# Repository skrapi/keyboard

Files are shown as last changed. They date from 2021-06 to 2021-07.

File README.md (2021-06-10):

# keyboard
Documenting my mechanical keyboard build

1. Put feet on case
1. Cut foam for M2 chip
1. Placed M2 Chip in keyboard
1. Plugged in computer
1. Flashing blue light on "1" key
1. Spacebar works
1. https://www.youtube.com/watch?v=usNx1_d0HbQ&t=84s
1. https://www.youtube.com/watch?v=cD5Zj-ZgMLA
1. Decided just to clip stabs, since I don't have lube
1. Mounted stabs with plastic washers
1. connected bluetooth and nfc antennas
1. Make sure that thehy are not in the way of the pcb mounting and switch connection holes
1. Cut case if needed to fit M2 boarD
1. Tested with online keyboard tester
1. Placed all the keycaps

## Designing keyboard
https://github.com/ruiqimao/keyboard-pcb-guide

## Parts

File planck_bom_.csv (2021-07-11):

Component | Description | Part | References | Value | Footprint | Quantity Per PCB | Datasheet
1 | Unpolarized capacitor, small symbol | C_Small | C7 C9 | 18p | C_0603_1608Metric | 2 | ~
2 | Unpolarized capacitor, small symbol | C_Small | C1 C2 C3 C4 C8 | 0.1u | C_0603_1608Metric | 5 | ~
3 | Unpolarized capacitor, small symbol | C_Small | C6 | 1u | C_0603_1608Metric | 1 | ~
4 | Unpolarized capacitor, small symbol | C_Small | C5 | 4.7u | C_0603_1608Metric | 1 | ~
5 | Diode | D | D1 D2 D5 D6 | D | D_SOD-123 | 4 | ~
6 | Zener diode, small symbol | D_Zener_Small | D3 D4 | ESD7951ST5G | D_SOD-923 | 2 | ~
7 | USB 2.0-only Type-C Receptacle connector | USB_C_Receptacle_USB2.0 | J1 | USB_C_Receptacle_USB2.0 | USB_C_Receptacle_Amphenol_12401548E4-2A | 1 | https://www.usb.org/sites/default/files/documents/usb_type-c.zip
8 |  | KEYSW | K1 K2 K3 K4 | KEYSW | SW_Cherry_MX_1.00u_PCB | 4
9 | Resistor | R | R3 R4 | 22 | R_0603_1608Metric | 2 | ~
10 | Resistor | R | R1 R2 | 5k1 | R_0603_1608Metric | 2 | ~
11 | Resistor | R | R5 R6 | 10k | R_0603_1608Metric | 2 | ~
12 |  | SW_PUSH | SW1 | SW_PUSH | SW_SPST_TL3342 | 1
13 | 16MHz, 32kB Flash, 2.5kB SRAM, 1kB EEPROM, USB 2.0, QFN-44 | ATmega32U4-M | U1 | ATmega32U4-M | QFN-44-1EP_7x7mm_P0.5mm_EP5.2x5.2mm | 1 | http://ww1.microchip.com/downloads/en/DeviceDoc/Atmel-7766-8-bit-AVR-ATmega16U4-32U4_Datasheet.pdf
14 | Four pin crystal, GND on pins 2 and 4, small symbol | Crystal_GND24_Small | Y1 | Crystal_GND24_Small | Crystal_SMD_SeikoEpson_FA238-4Pin_3.2x2.5mm | 1 | ~
Component Groups: | 14
Component Count: | 29
Fitted Components: | 29
Number of PCBs: | 1
Total components: | 29
Schematic Version:
Schematic Date:
PCB Variant: | default
BoM Date: | Sat 10 Jul 2021 16:44:31
Schematic Source: | planck.kicad_sch
KiCad Version: | Eeschema 5.99.0-unknown-3f6811f413~130~ubuntu20.10.1

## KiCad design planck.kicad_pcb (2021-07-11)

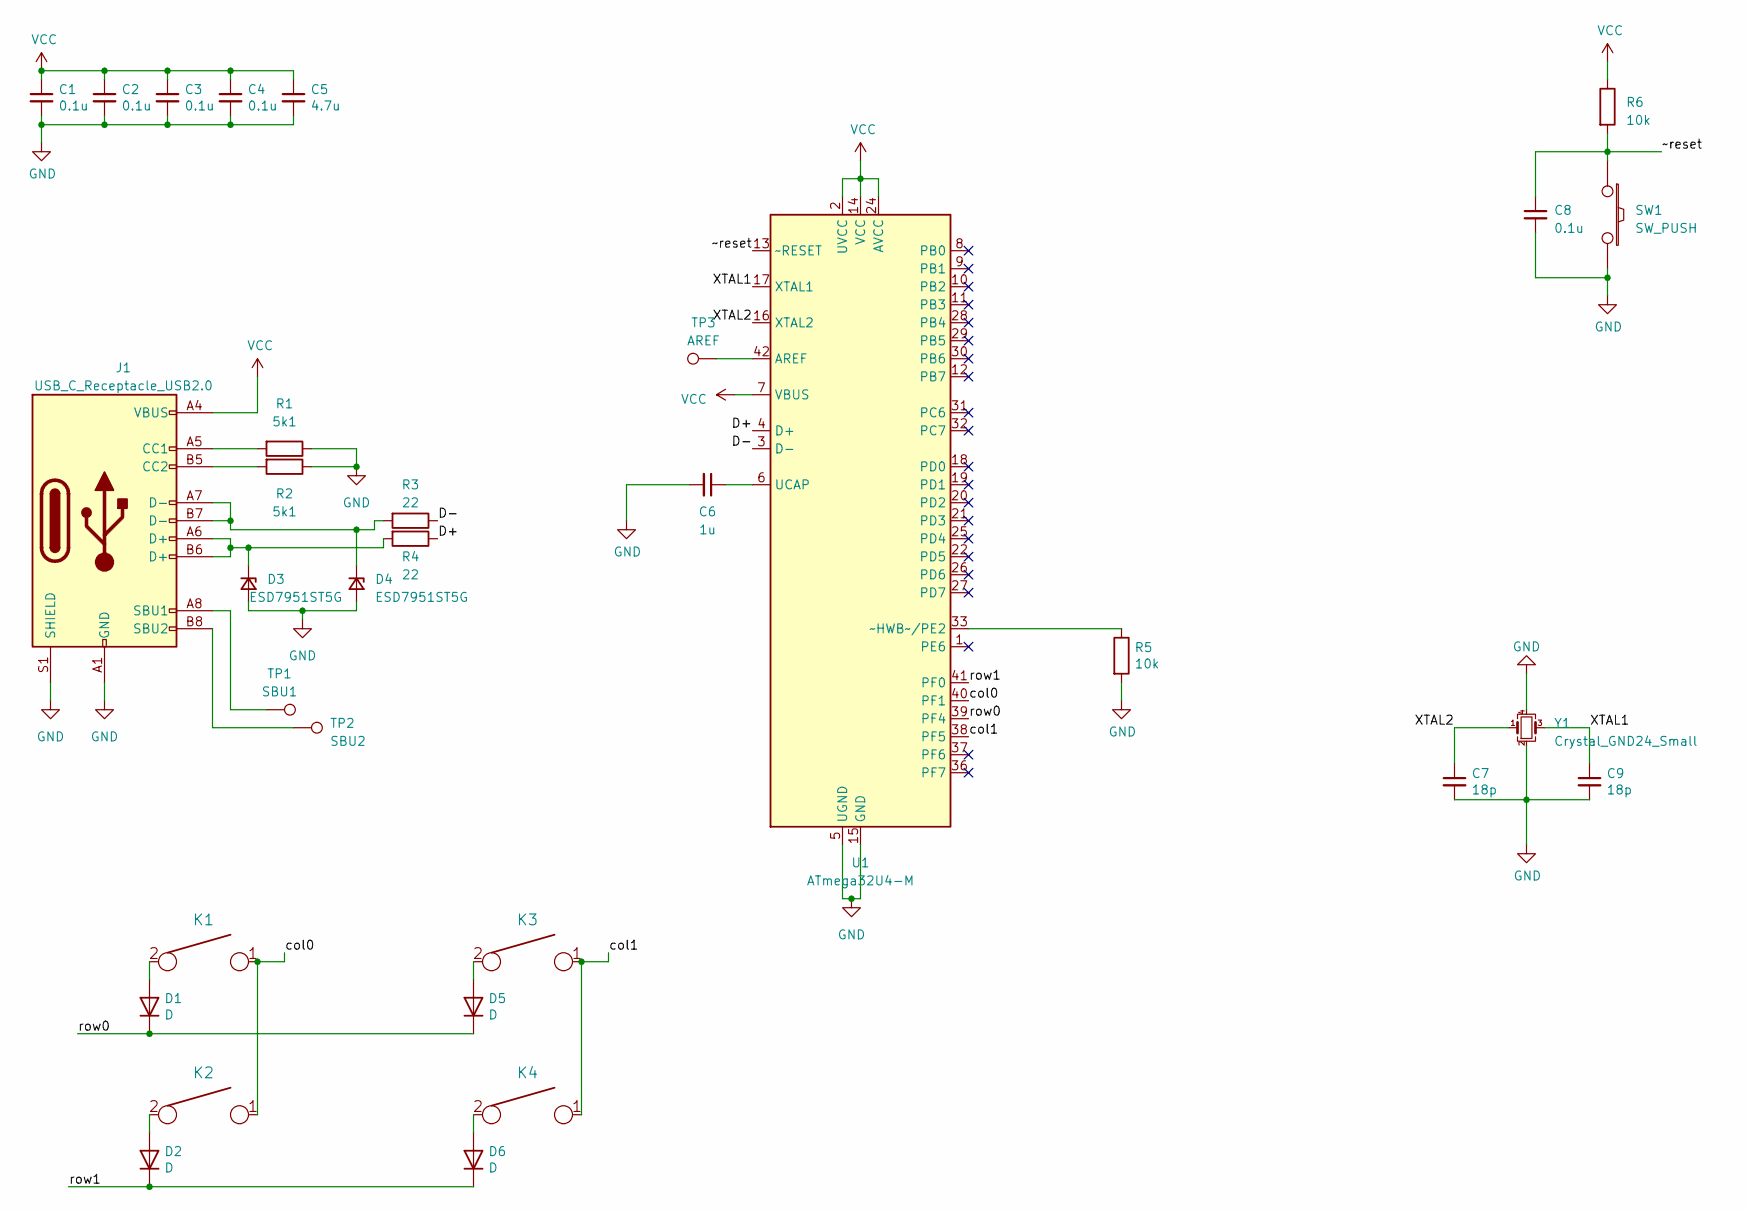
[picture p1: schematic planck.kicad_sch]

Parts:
C1, C2, C3, C4, C8: 0.1u; C_0402_1005Metric
C5: 4.7u; C_0402_1005Metric
C6: 1u; C_0402_1005Metric
C7, C9: 18p; C_0402_1005Metric
D1, D2, D5, D6: D; D_SOD-123
D3, D4: ESD7951ST5G; D_SOD-923
J1: USB_C_Receptacle_USB2.0; USB_C_Receptacle_Amphenol_12401610E4-2A
K1, K2, K3, K4: KEYSW; SW_Cherry_MX_1.00u_PCB
R1, R2: 5k1; R_0402_1005Metric
R3, R4: 22; R_0402_1005Metric
R5, R6: 10k; R_0402_1005Metric
SW1: SW_PUSH; SW_SPST_CK_RS282G05A3
TP1: SBU1; TestPoint_Pad_D1.0mm
TP2: SBU2; TestPoint_Pad_D1.0mm
TP3: AREF; TestPoint_Pad_D1.0mm
U1: ATmega32U4-M; QFN-44-1EP_7x7mm_P0.5mm_EP5.2x5.2mm
Y1: Crystal_GND24_Small; Crystal_SMD_SeikoEpson_FA238-4Pin_3.2x2.5mm

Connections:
/D+: R4.1, U1.4 (D+)
/D-: R3.1, U1.3 (D-)
/XTAL1: C9.1, U1.17 (XTAL1), Y1.3
/XTAL2: C7.1, U1.16 (XTAL2), Y1.1
/col0: K1.1, K2.1, U1.40 (PF1)
/col1: K3.1, K4.1, U1.38 (PF5)
/row0: D1.1 (K), D5.1 (K), U1.39 (PF4)
/row1: D2.1 (K), D6.1 (K), U1.41 (PF0)
/~reset: C8.1, R6.2, SW1.1, U1.13 (~RESET)
GND: C1.2, C2.2, C3.2, C4.2, C5.2, C6.2, C7.2, C8.2, C9.2, D3.2 (A), D4.2 (A), J1.A1 (GND), J1.A12 (GND), J1.B1 (GND), J1.B12 (GND), J1.S1 (SHIELD), R1.1, R2.1, R5.2, SW1.2, U1.5 (UGND), U1.15 (GND), U1.23 (GND), U1.35 (GND), U1.43 (GND), U1.45 (GND), Y1.2, Y1.4
unnamed: C6.1, U1.6 (UCAP)
unnamed: D1.2 (A), K1.2
unnamed: D2.2 (A), K2.2
unnamed: D3.1 (K), J1.A6 (D+), J1.B6 (D+), R4.2
unnamed: D4.1 (K), J1.A7 (D-), J1.B7 (D-), R3.2
unnamed: D5.2 (A), K3.2
unnamed: D6.2 (A), K4.2
unnamed: J1.A5 (CC1), R1.2
unnamed: J1.A8 (SBU1), TP1.1
unnamed: J1.B5 (CC2), R2.2
unnamed: J1.B8 (SBU2), TP2.1
unnamed: R5.1, U1.33 (~HWB~/PE2)
unnamed: TP3.1, U1.42 (AREF)
VCC: C1.1, C2.1, C3.1, C4.1, C5.1, J1.A4 (VBUS), J1.A9 (VBUS), J1.B4 (VBUS), J1.B9 (VBUS), R6.1, U1.2 (UVCC), U1.7 (VBUS), U1.14 (VCC), U1.24 (AVCC), U1.34 (VCC), U1.44 (AVCC)

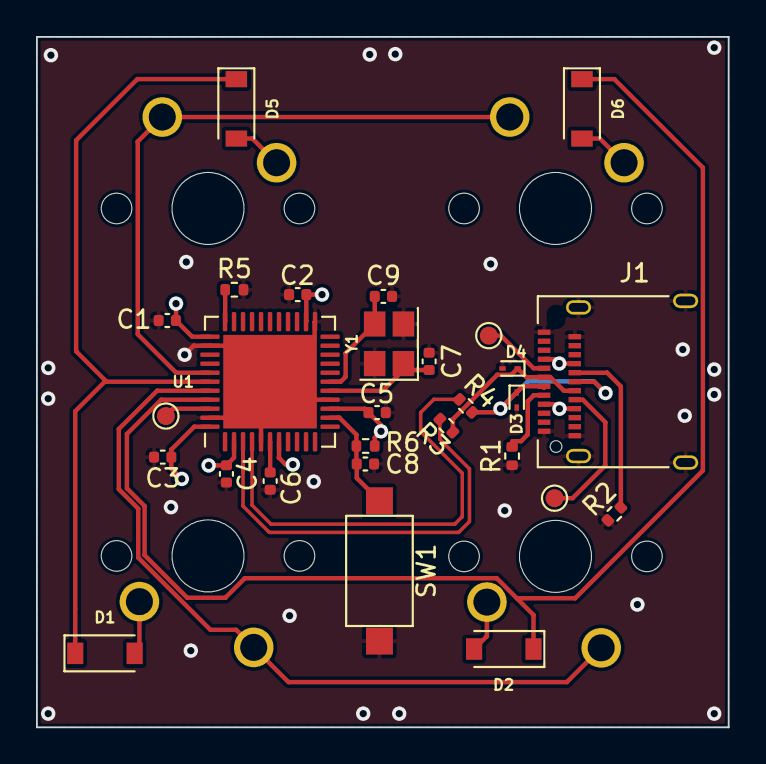
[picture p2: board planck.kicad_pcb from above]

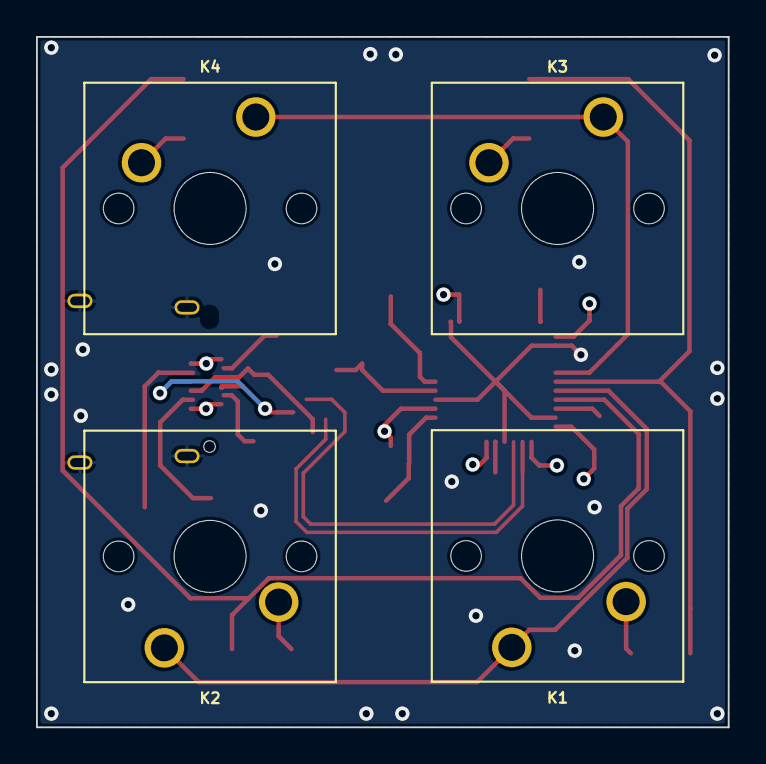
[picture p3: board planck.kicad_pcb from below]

Board: 4 copper layers, 38.4 x 38.4 mm, 32 parts (4 on the bottom side), 24 nets.

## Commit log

2021-06-09 added submodules
    [planck.kicad_pcb, planck.sch]
2021-06-10 Created schematic
    [planck.sch]
2021-06-19 Upgraded to kicad 6
    [planck.kicad_sch]
2021-06-19 added basic layout
    [planck.kicad_pcb]
2021-06-19 poured gnd plane
2021-06-19 poured fills
    [planck.kicad_pcb]
2021-06-19 started routing
    [planck.kicad_pcb, planck.kicad_sch]
2021-06-20 routed crystal
    [planck.kicad_pcb]
2021-07-04 finishing it off
    [planck.kicad_pcb, planck.kicad_sch]
2021-07-04 switched pins for switches
    [planck.kicad_pcb, planck.kicad_sch]
2021-07-04 finished layout
    [planck.kicad_pcb, planck.kicad_sch]
2021-07-11 added digikey library
    [planck.kicad_pcb, planck.kicad_sch, planck_bom_.csv]
2021-07-11 added new usb c
    [planck.kicad_pcb, planck.kicad_sch]
